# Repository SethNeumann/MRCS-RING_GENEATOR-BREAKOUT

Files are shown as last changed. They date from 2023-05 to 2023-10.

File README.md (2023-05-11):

# REPO NAME: MRCS-RING_GENERATOR-BREAKOUT
## License: Creative Commons Attribution-NonCommercial-ShareAlike

Board for potted ring generator module. Mounts in 70mm Tyco Track (MD) inputs power (screw term and barrel jack), output, straps to select frequency,
optionally add pads for other varieties. The modules are long since MD and data sheets are not available for the PCR-SIN01=V12F00A which I bought oneBay
some suppliers claim to have them.

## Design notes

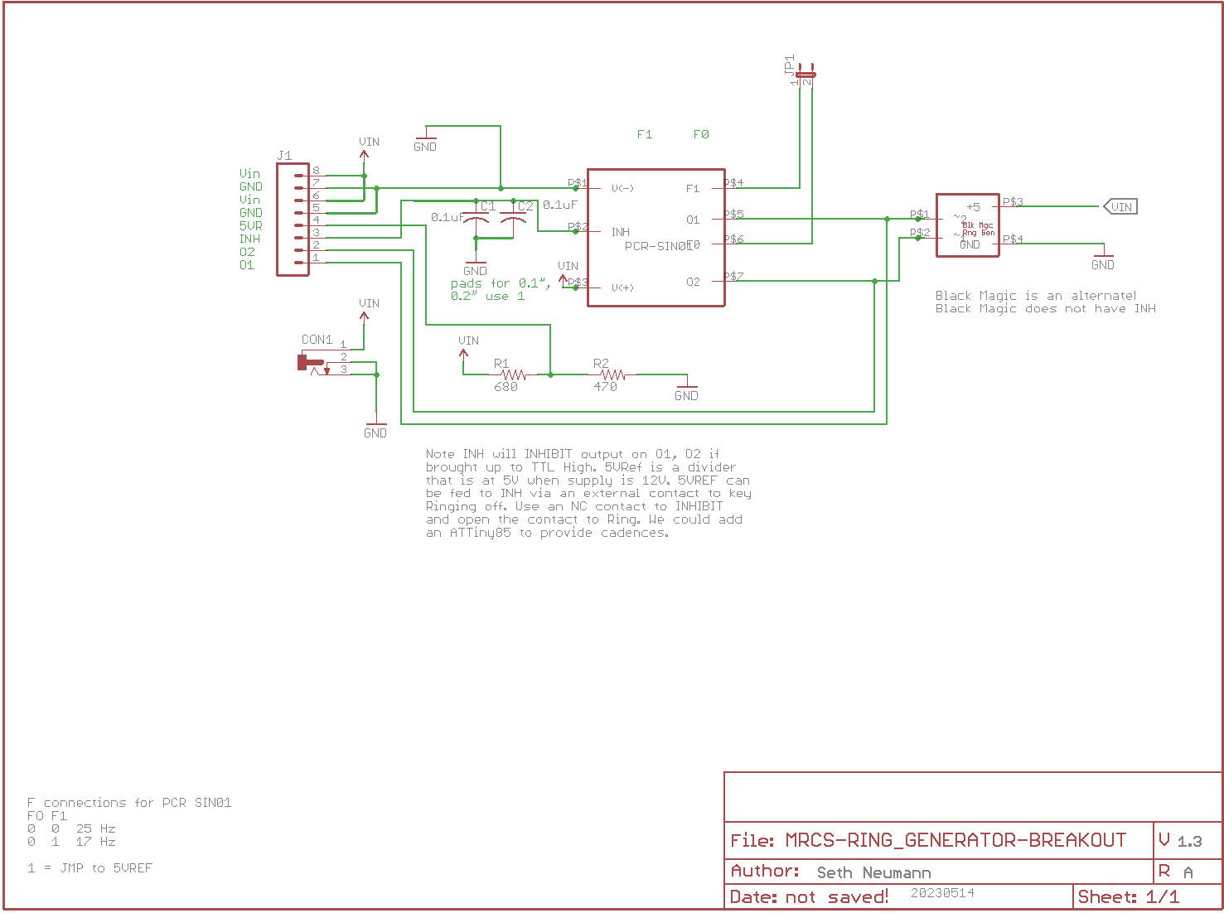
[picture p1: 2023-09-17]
Ringing Generator Schematic V1_3.png

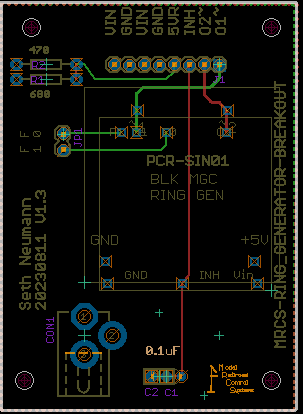
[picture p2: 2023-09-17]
Ringing Generator top layout V1_3.png

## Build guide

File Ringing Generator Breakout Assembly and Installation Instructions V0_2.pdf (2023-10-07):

Page 1 | www.modelrailroadcontrolsystems.com | Sept 17, 2023

# Ringing Generator Module Break Out Board

Revision 0.2 10/07/2023

Seth Neumann, seth@modelrailroadcontrolsystems.com

This document describes the Ringing Generator Module Break Out Board and how to assemble and install it. This board provides a convenient mounting for several types of PowerDsine ™ and Black Magic ™ modules which produce 20Hz ringing signals from 5- or 12-volt DC inputs. As far as I can tell, these modules are all out of production, but they appear for sale on eBay and Telephone Collectors’ lists from time to time. These are handy for demonstrations, model railroad dispatching systems and community theatre applications.

Revision History
V0.1 – first pass – September 17, 2023
V0.2 – minor changes – October 7, 2023

## Table of Contents

7.1. 12

## Table of Figures

## Table of Tables

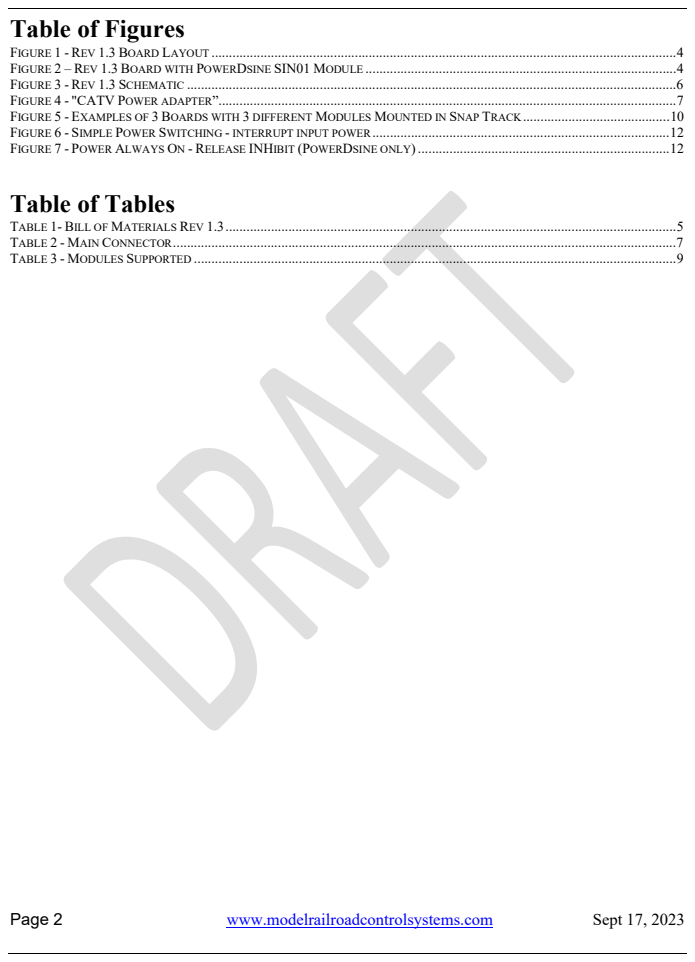
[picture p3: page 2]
Page 2; www.modelrailroadcontrolsystems.com; Sept 17, 2023

FIGURE 1 - REV 1.3 BOARD LAYOUT ..................................................................................................................................... 4
FIGURE 2 – REV 1.3 BOARD WITH POWERDSINE SIN01 MODULE ......................................................................................... 4
FIGURE 3 - REV 1.3 SCHEMATIC ............................................................................................................................................ 6
FIGURE 4 - "CATV POWER ADAPTER”................................................................................................................................... 7
FIGURE 5 - EXAMPLES OF 3 BOARDS WITH 3 DIFFERENT MODULES MOUNTED IN SNAP TRACK .......................................... 10
FIGURE 6 - SIMPLE POWER SWITCHING - INTERRUPT INPUT POWER ..................................................................................... 12
FIGURE 7 - POWER ALWAYS ON - RELEASE INHIBIT (POWERDSINE ONLY) ........................................................................ 12

TABLE 1- BILL OF MATERIALS REV 1.3 ................................................................................................................................. 5
TABLE 2 - MAIN CONNECTOR ................................................................................................................................................ 7
TABLE 3 - MODULES SUPPORTED .......................................................................................................................................... 9

Page 3 | www.modelrailroadcontrolsystems.com | Sept 17, 2023

### 1 INTRODUCTION

This document describes the Ringing Generator Module Break Out Board and how to assemble and install it. This board provides a convenient mounting for several types of PowerDsine ™ and Black Magic ™ modules which produce 20Hz sinewave ringing signals from 5- or 12-volt DC inputs. As far as I can tell, these modules are out of production, but they appear for sale on eBay and Telephone Collectors’ lists from time to time. These are handy for demonstrations, model railroad dispatching systems and community theatre applications.

- Small Footprint 2 x 2.75” (5x7 CM) by ~ .5” high depending on module used.
- Fits in MRCS standard 7CM “Snap Track”
- Power connections on 2.54 mm screw terminals or 2.1mm Barrel Jack. One 12V "Wall Wart" can be daisy chained to power several adapters using the 12V screw terminal connections.
- Supports the Inhibit (INH) function on PowerDsine modules and a voltage divider provides a convenient 5V reference voltage so that an external contact (NC to inhibit) can gate ringing.
- Available as a panel of two bare boards, you supply the module. If you have modules but want us to assemble it, please contact us at sales@modelrailroadcontrolsystems.com

Schematic, circuit board layouts and CAD files are available on the product page on our website and on my GitHub page https://github.com/SethNeumann.

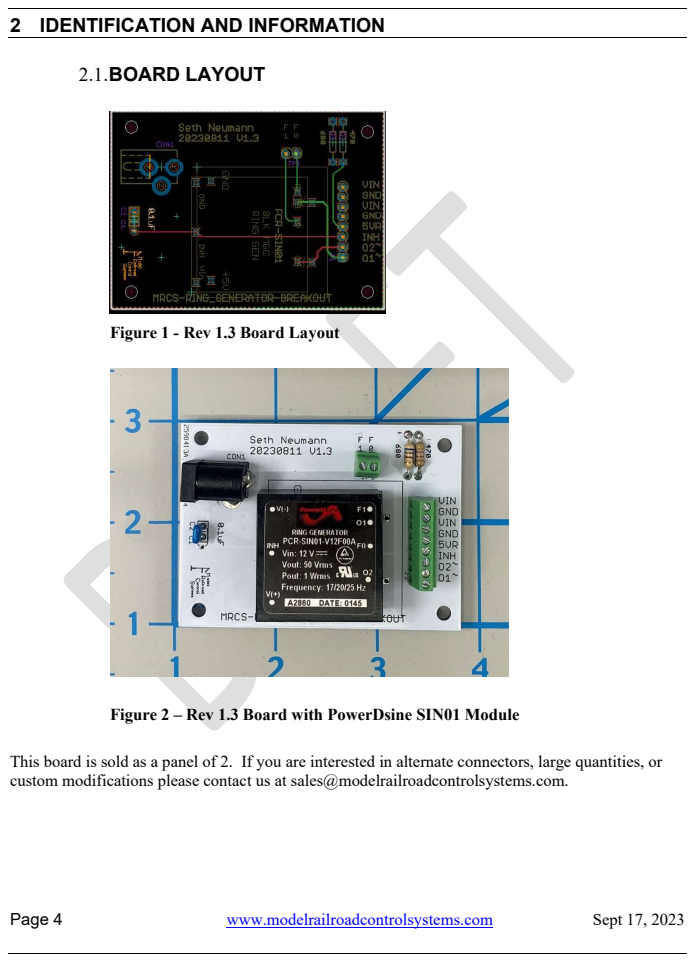
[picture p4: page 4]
Page 4; www.modelrailroadcontrolsystems.com; Sept 17, 2023; 2.1.BOARD LAYOUT

2 IDENTIFICATION AND INFORMATION

Figure 1 - Rev 1.3 Board Layout

Figure 2 – Rev 1.3 Board with PowerDsine SIN01 Module

This board is sold as a panel of 2. If you are interested in alternate connectors, large quantities, or
custom modifications please contact us at sales@modelrailroadcontrolsystems.com.

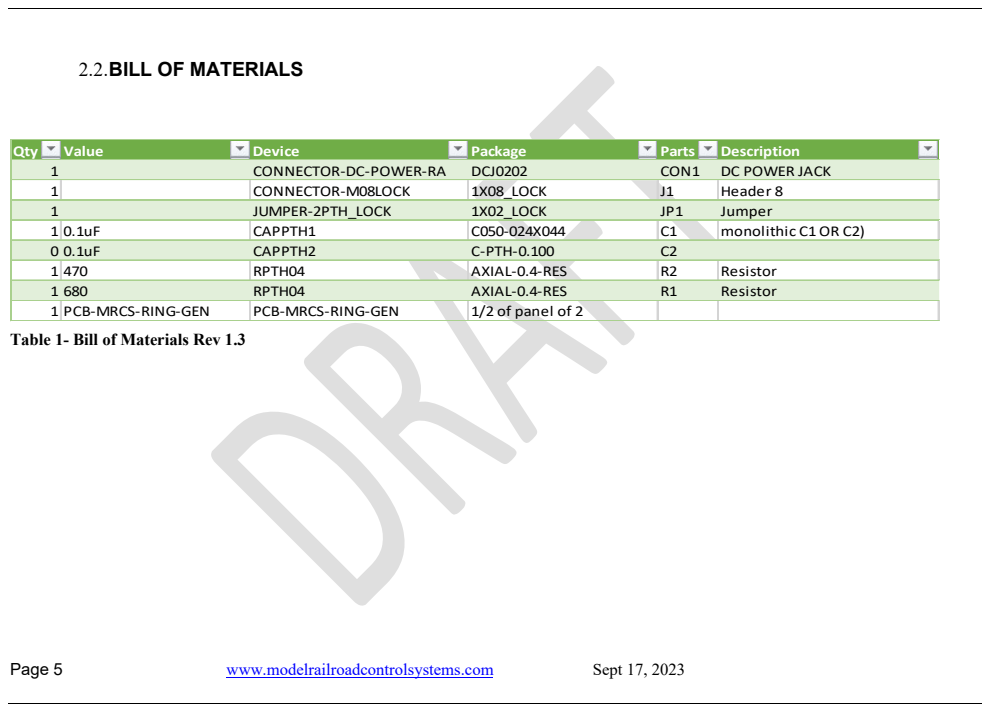
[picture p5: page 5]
Page 5; www.modelrailroadcontrolsystems.com; Sept 17, 2023; Qty; Value; Device; Package; Parts; Description; CONNECTOR-DC-POWER-RA; DCJ0202; CON1 DC POWER JACK; CONNECTOR-M08LOCK; 1X08_LOCK; Header 8; JUMPER-2PTH_LOCK; 1X02_LOCK; Jumper; CAPPTH1; monolithic C1 OR C2); CAPPTH2; C-PTH-0.100; RPTH04; AXIAL-0.4-RES; Resistor; 1 PCB-MRCS-RING-GEN; PCB-MRCS-RING-GEN; 1/2 of panel of 2

2.2.BILL OF MATERIALS

Table 1- Bill of Materials Rev 1.3

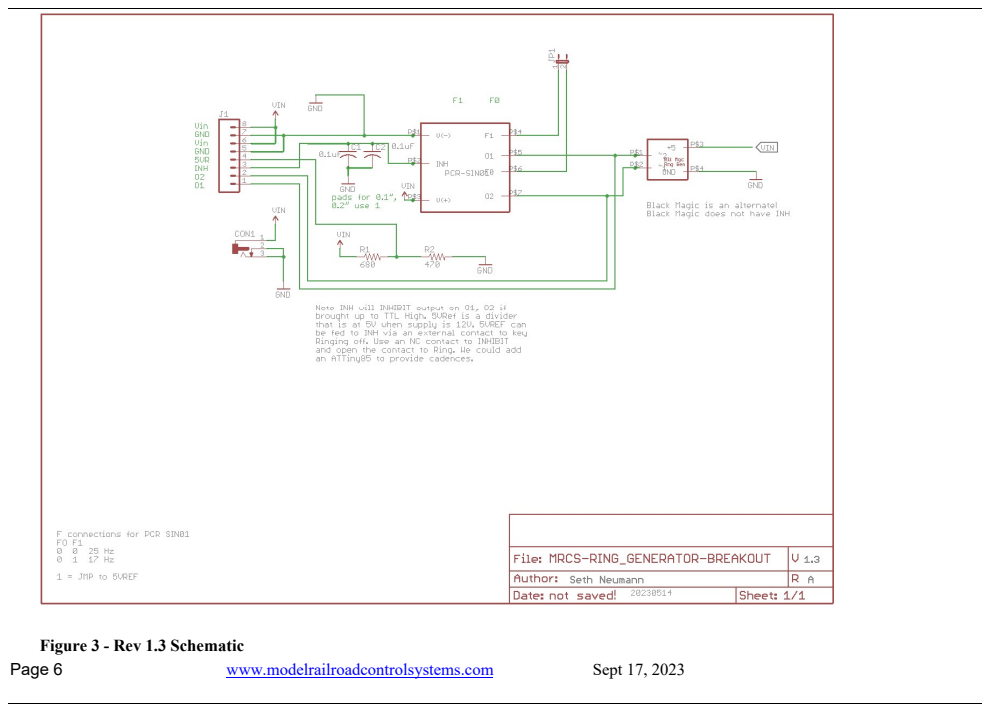
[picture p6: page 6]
Page 6; www.modelrailroadcontrolsystems.com; Sept 17, 2023

Figure 3 - Rev 1.3 Schematic

Page 7 | www.modelrailroadcontrolsystems.com | Sept 17, 2023

### 3 OPTIONS

3.1.CONNECTORS

The main (J1) Connector is on 2.54mm (0.100”) centers. The +V and GND inputs are in parallel with the 2.1 x 5.5 mm. barrel jack and may be used to daisy chain power among multiple Ring Generator breakouts or other 12V loads, subject to the capacity of the 12V wall wart. Note that some Black Magic ™ devices require 5V, so check, also check the current requirements of your module (see table below), if so just use a 5V power supply.

You can omit the barrel jack if wiring directly from a 12VDC auxiliary bus. You can also use a “CATV Power adapter” to plug power from an power auxiliary bus into the barrel jack.

Figure 4 - "CATV Power adapter”

Designation | Comment
VIN | Input Voltage – select for your module, in parallel with DC Power Jack
GND | Negative connection, usually ground
VIN | Input Voltage – select for your module, in parallel with DC Power Jack
GND | Negative connection, usually ground
5VR | For PowerDsine modules – center of voltage divider to INHibit ringing
INH | INHIBIT: Apply 5V here to inhibit ringing, can also use external logic level device such as an Arduino to generate arbitrary ring cadences. Be sure to ground the Arduino and ringing generator breakout together.
O2~ | AC output 20/25~ at 50-85V depending on module
O1~ | AC output 20/25~ at 50-85V depending on module

Table 2 - Main Connector

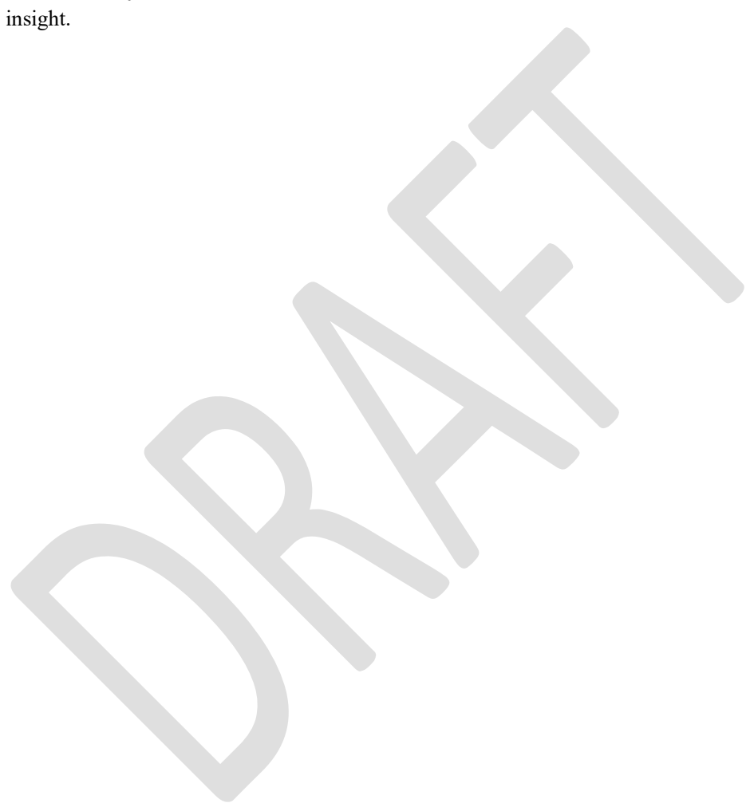
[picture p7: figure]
insight.

Page 8 | www.modelrailroadcontrolsystems.com | Sept 17, 2023

3.2.FREQUENCY SELECTION (PCR-SIN01ONLY)

The PCR-SIN01 states on the case that it can operate at 16.7/20/25 Hz. Perusal of SIN06 (I don’t have an example to test) documentation suggests that tying F0/F1 to 5V will result in other frequencies. I found that the SIN01 with F0/F1 left floating will produce 25 Hz ringing (works fine for a straight-line ringer) and tying F1 to 5VR results in 16.7 Hz. I wasn’t able to get F0 to do anything. Interestingly, grounding F1 produced the same (16.7Hz) result, but the DC position was offset slightly. Connecting both to 5VR also produced 16.7 Hz. My sample(s) may have been defective or there may be some other function of F0 that I am unaware of. Please contact me at the email address above if you have any

Page 9 | www.modelrailroadcontrolsystems.com | Sept 17, 2023

### 4 ASSEMBLY

All components are through-hole technology with wire leads for ease of DIY assembly. The general rule is to install the lowest components first, working towards components that are higher off the board. This enables you to support the low components as you solder them. The suggested order assumes you are using the barrel connector. If you choose to use different connectors, check the heights, and vary the build order accordingly.

[ ] Resistors

[ ] Install resistors R1, R2, these are voltage divider that yields ~5V with a 12V input. If you are using Black Magic ™ modules, not using the inhibit function or are using an Arduino or other logic level device to control the output, you can omit the resistors.

[ ] Screw Terminals

[ ] Install J1. This is an 8 position 2.54 mm screw terminal. Note that only the O1~ and O2~ terminals are required. If you aren’t using the INHibit function and don’t need to daisy chain power, the other positions can be left open and a 2 position terminal may be used.
[ ] Install the 2 position jumper or screw terminal for F0/F1. This is used by the PowerDsine PCR-SIN01-V12F00A. Most users will omit this connector.

[ ] Capacitors

C1 and C2 are alternates at 0.1” or 0.2” spacing and provide noise protection on the INHibit line. You can omit them for Black Magic ™ modules. I use monolithic caps for this application, and they come in both footprints

[ ] Barrel Jack

[ ] Install the DC Power barrel jack, if used

[ ] Ring Generator Module

[ ] Install your ringing generator module with pads provided. (I made EAGLE CAD “Library models” of the various modules I have. Contact me if you have something different and I can probably make a model for it and make a board version using it).

Module | INH? | Input V | Input Current Idle | Input Current Active | Ring Volts Out | Nominal Freq/Func
PowerDsine PCR SIN01 | Y | 12 VDC | 52 mA @ 12V | 270 mA | 50 VAC | 25 Hz Sine
PowerDsine PCR SQR05 | Y | 12 VDC | 63 mA @ 12V | 325 mA | 70 VAC | 20 Hz Square
Black Magic | N | 5VDC | 165 mA @ 5V | 1.05 A @ 5V | 86 VAC | 20 Hz Square

Table 3 - Modules Supported

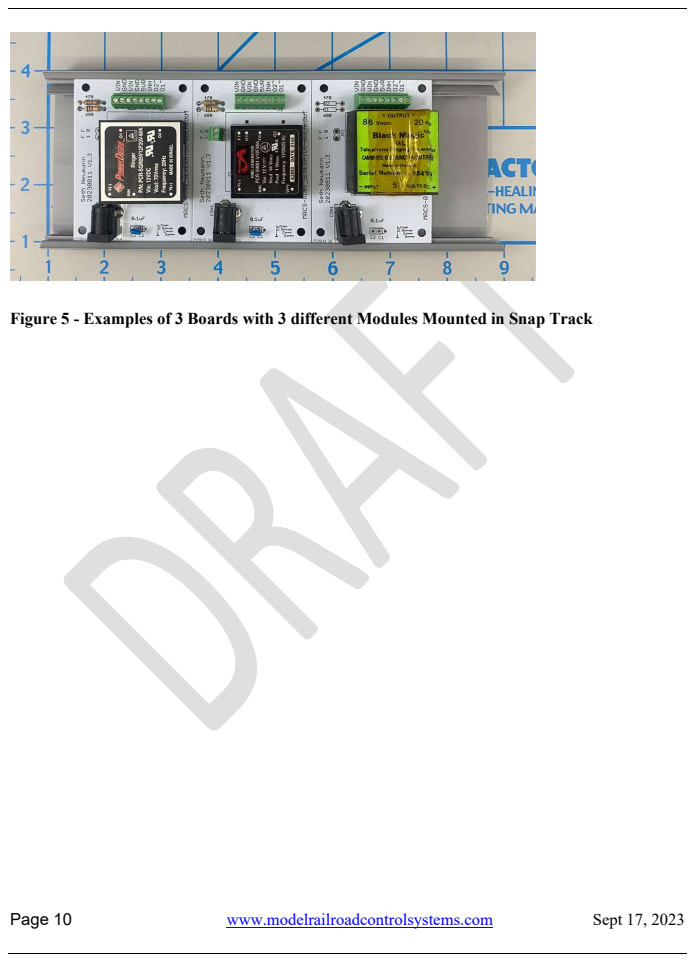
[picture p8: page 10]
Page 10; www.modelrailroadcontrolsystems.com; Sept 17, 2023

Figure 5 - Examples of 3 Boards with 3 different Modules Mounted in Snap Track

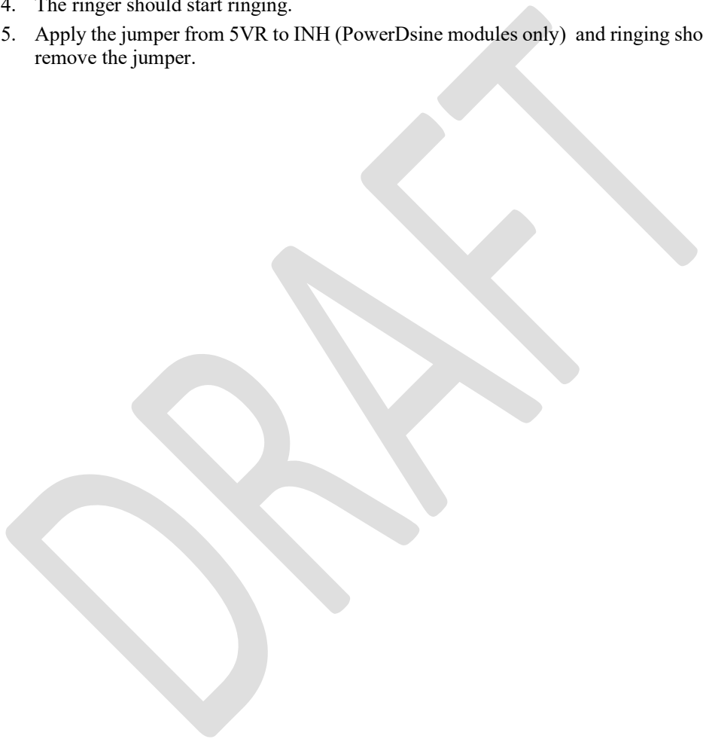
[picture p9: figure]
remove the jumper.

Page 11 | www.modelrailroadcontrolsystems.com | Sept 17, 2023

### 5 TESTING

Testing your Ringing Generator board is quick and simple:

1. Connect a suitable ringer (say a C4A from a 500 set or just put a 500 set) across the O1~ and O2~ terminals.
2. Prepare a jumper wire with one end in the 5VR terminal and the other stripped.
3. Apply power (as determined by your module) to either the barrel jack or the screw terminal.
4. The ringer should start ringing.
5. Apply the jumper from 5VR to INH (PowerDsine modules only) and ringing should stop until you

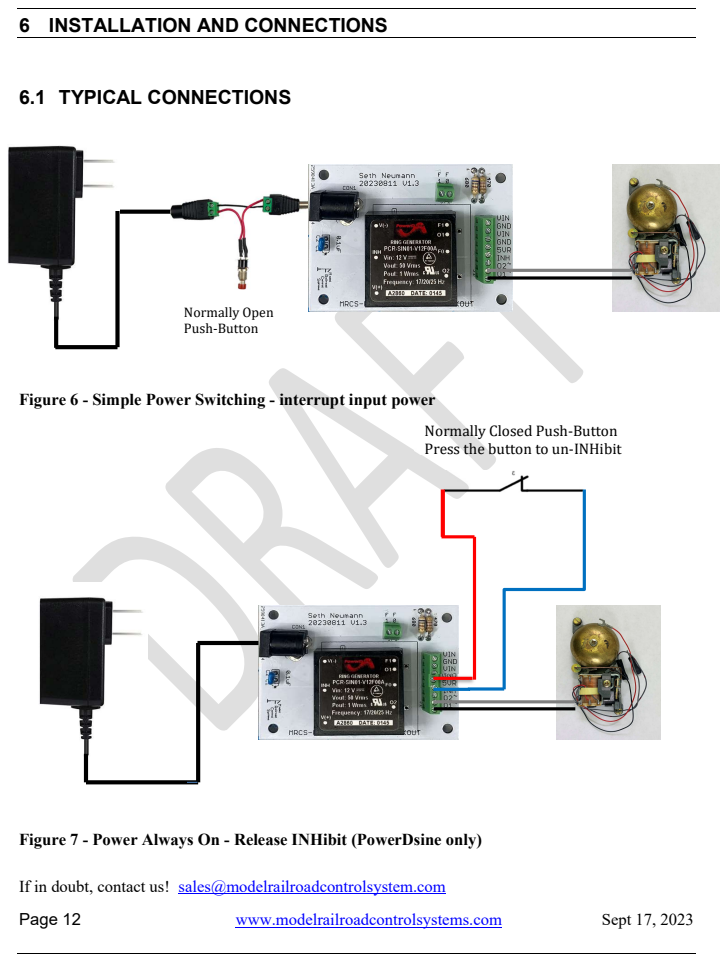
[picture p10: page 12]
Page 12; www.modelrailroadcontrolsystems.com; Sept 17, 2023; 6.1 TYPICAL CONNECTIONS; Normally Open Push-Button

6 INSTALLATION AND CONNECTIONS

Figure 6 - Simple Power Switching - interrupt input power

Normally Closed Push-Button
Press the button to un-INHibit

Figure 7 - Power Always On - Release INHibit (PowerDsine only)

If in doubt, contact us! sales@modelrailroadcontrolsystem.com

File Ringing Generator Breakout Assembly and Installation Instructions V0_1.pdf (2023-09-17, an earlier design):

Page 1 | www.modelrailroadcontrolsystems.com | Sept 17, 2023

# Ringing Generator Module Break Out Board

Revision 0.1 09/17/2023

Seth Neumann, seth@modelrailroadcontrolsystems.com

This document describes the Ringing Generator Module Break Out Board and how to assemble and install it. This board provides a convenient mounting for several types of PowerDsine ™ and Black Magic ™ modules which produce 20Hz ringing signals from 5- or 12-volt DC inputs. As far as I can tell, these modules are all out of production, but they appear for sale on eBay and Telephone Collectors’ lists from time to time. These are handy for demonstrations, model railroad dispatching systems and community theatre applications.

Revision History
V0.1 – first pass – September 17, 2023

## Table of Contents

7.1. 12

## Table of Figures

## Table of Tables

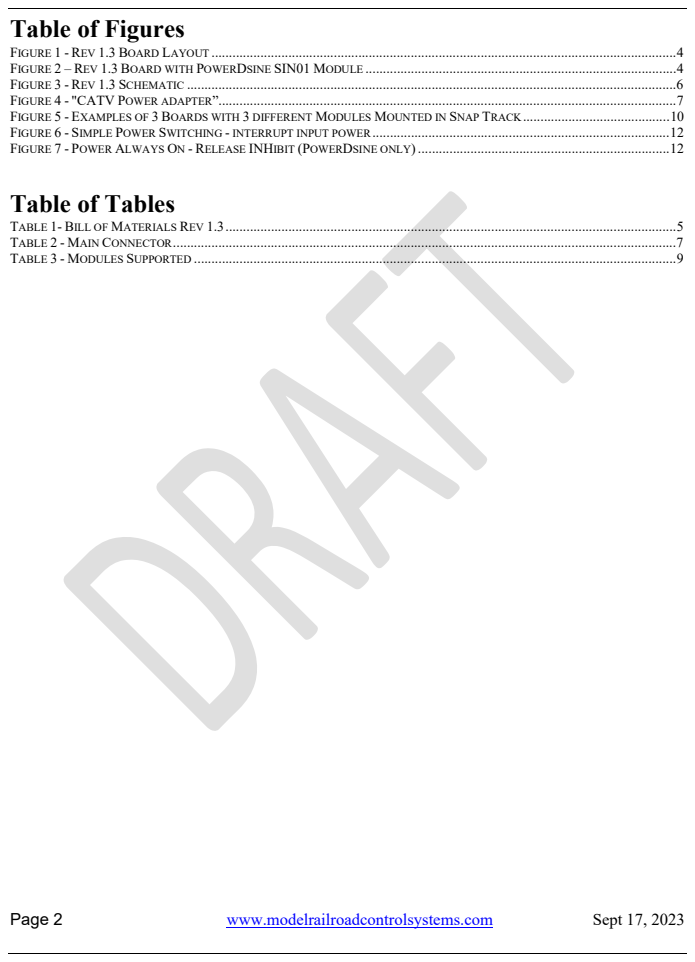
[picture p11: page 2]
Page 2; www.modelrailroadcontrolsystems.com; Sept 17, 2023

FIGURE 1 - REV 1.3 BOARD LAYOUT ..................................................................................................................................... 4
FIGURE 2 – REV 1.3 BOARD WITH POWERDSINE SIN01 MODULE ......................................................................................... 4
FIGURE 3 - REV 1.3 SCHEMATIC ............................................................................................................................................ 6
FIGURE 4 - "CATV POWER ADAPTER”................................................................................................................................... 7
FIGURE 5 - EXAMPLES OF 3 BOARDS WITH 3 DIFFERENT MODULES MOUNTED IN SNAP TRACK .......................................... 10
FIGURE 6 - SIMPLE POWER SWITCHING - INTERRUPT INPUT POWER ..................................................................................... 12
FIGURE 7 - POWER ALWAYS ON - RELEASE INHIBIT (POWERDSINE ONLY) ........................................................................ 12

TABLE 1- BILL OF MATERIALS REV 1.3 ................................................................................................................................. 5
TABLE 2 - MAIN CONNECTOR ................................................................................................................................................ 7
TABLE 3 - MODULES SUPPORTED .......................................................................................................................................... 9

Page 3 | www.modelrailroadcontrolsystems.com | Sept 17, 2023

### 1 INTRODUCTION

This document describes the Ringing Generator Module Break Out Board and how to assemble and install it. This board provides a convenient mounting for several types of PowerDsine ™ and Black Magic ™ modules which produce 20Hz sinewave ringing signals from 5- or 12-volt DC inputs. As far as I can tell, these modules are out of production, but they appear for sale on eBay and Telephone Collectors’ lists from time to time. These are handy for demonstrations, model railroad dispatching systems and community theatre applications.

- Small Footprint 2 x 2.75” (5x7 CM) by ~ .5” high depending on module used.
- Fits in MRCS standard 7CM “Snap Track”
- Power connections on 2.54 mm screw terminals or 2.1mm Barrel Jack. One 12V "Wall Wart" can be daisy chained to power several adapters using the 12V screw terminal connections.
- Supports the Inhibit (INH) function on PowerDsine modules and a voltage divider provides a convenient 5V reference voltage so that an external contact (NC to inhibit) can gate ringing.
- Available as a panel of two bare boards, you supply the module. If you have modules but want us to assemble it, please contact us at sales@modelrailroadcontrolsystems.com

Schematic, circuit board layouts and CAD files are available on the product page on our website and on my GitHub page https://github.com/SethNeumann.

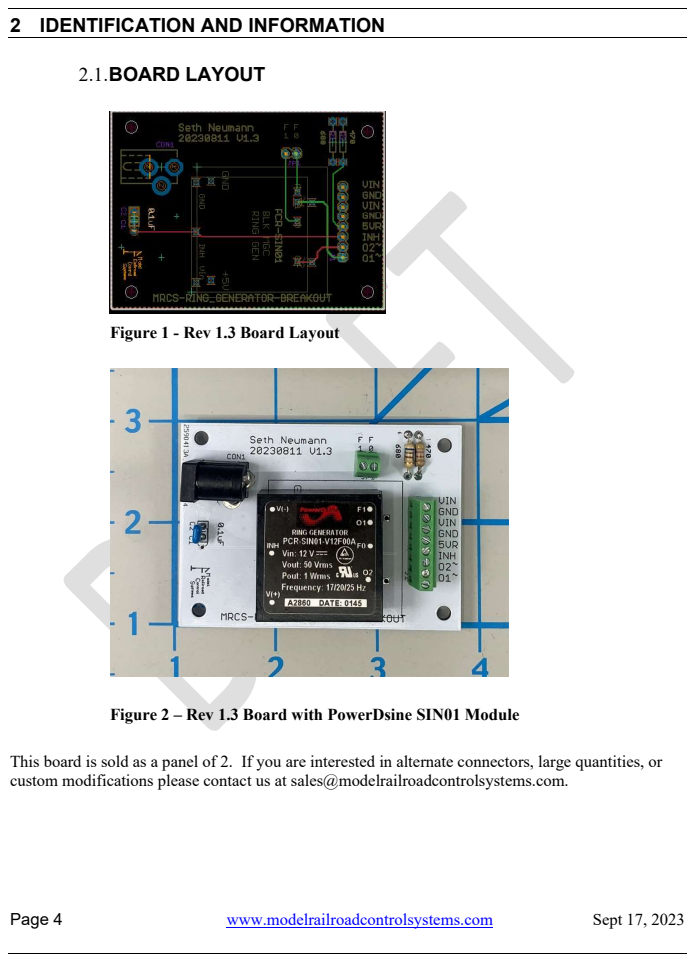
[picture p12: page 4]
Page 4; www.modelrailroadcontrolsystems.com; Sept 17, 2023; 2.1.BOARD LAYOUT

2 IDENTIFICATION AND INFORMATION

Figure 1 - Rev 1.3 Board Layout

Figure 2 – Rev 1.3 Board with PowerDsine SIN01 Module

This board is sold as a panel of 2. If you are interested in alternate connectors, large quantities, or
custom modifications please contact us at sales@modelrailroadcontrolsystems.com.

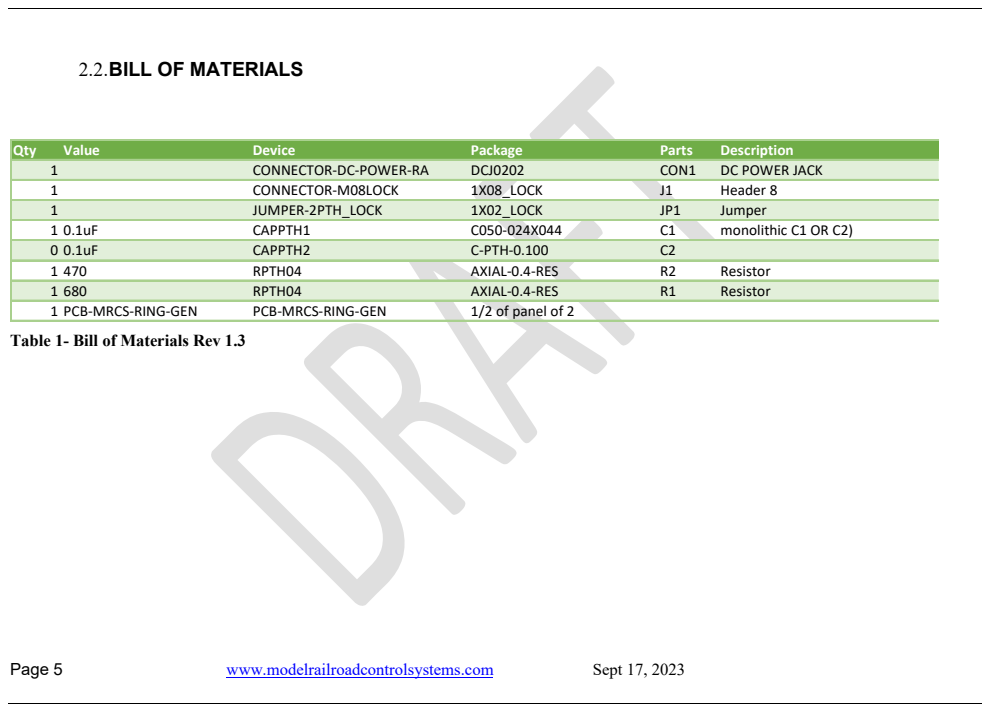
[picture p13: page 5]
Page 5; www.modelrailroadcontrolsystems.com; Sept 17, 2023; Qty; Value; Device; Package; Parts; Description; CONNECTOR-DC-POWER-RA; DCJ0202; CON1; DC POWER JACK; CONNECTOR-M08LOCK; 1X08_LOCK; Header 8; JUMPER-2PTH_LOCK; 1X02_LOCK; Jumper; CAPPTH1; monolithic C1 OR C2); CAPPTH2; C-PTH-0.100; RPTH04; AXIAL-0.4-RES; Resistor; 1 PCB-MRCS-RING-GEN; PCB-MRCS-RING-GEN; 1/2 of panel of 2

2.2.BILL OF MATERIALS

Table 1- Bill of Materials Rev 1.3

Page 6; www.modelrailroadcontrolsystems.com; Sept 17, 2023

Figure 3 - Rev 1.3 Schematic

Page 7 | www.modelrailroadcontrolsystems.com | Sept 17, 2023

### 3 OPTIONS

3.1.CONNECTORS

The main (J1) Connector is on 2.54mm (0.100”) centers. The +V and GND inputs are in parallel with the 2.1 x 5.5 mm. barrel jack and may be used to daisy chain power among multiple Ring Generator breakouts or other 12V loads, subject to the capacity of the 12V wall wart. Note that some Black Magic ™ devices require 5V, so check, also check the current requirements of your module (see table below), if so just use a 5V power supply.

You can omit the barrel jack if wiring directly from a 12VDC auxiliary bus. You can also use a “CATV Power adapter” to plug power from an power auxiliary bus into the barrel jack.

Figure 4 - "CATV Power adapter”

Designation | Comment
VIN | Input Voltage – select for your module, in parallel with DC Power Jack
GND | Negative connection, usually ground
VIN | Input Voltage – select for your module, in parallel with DC Power Jack
GND | Negative connection, usually ground
5VR | For PowerDsine modules – center of voltage divider to INHibit ringing
INH | INHIBIT: Apply 5V here to inhibit ringing, can also use external logic level device such as an Arduino to generate arbitrary ring cadences. Be sure to ground the Arduino and ringing generator breakout together.
O2~ | AC output 20~ at 50-85V depending on module
O1~ | AC output 20~ at 50-85V depending on module

Table 2 - Main Connector

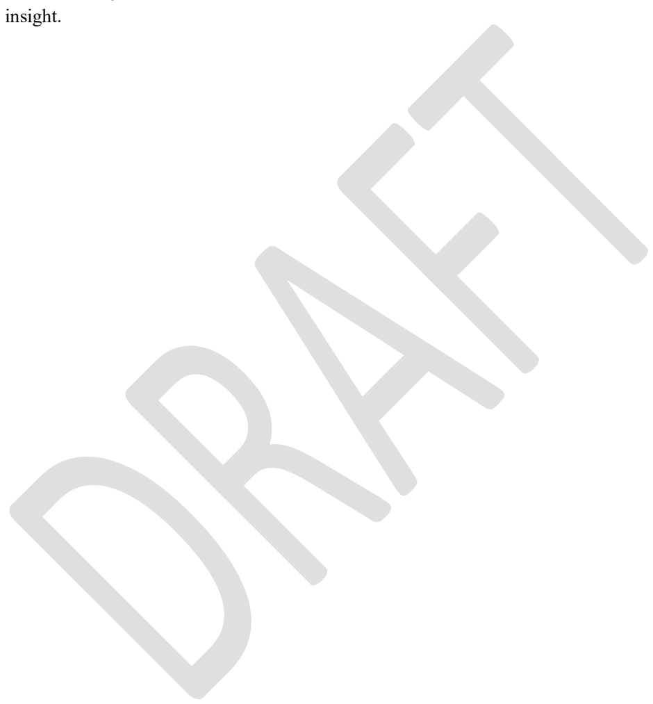
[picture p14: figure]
insight.

Page 8 | www.modelrailroadcontrolsystems.com | Sept 17, 2023

3.2.FREQUENCY SELECTION (PCR-SIN01ONLY)

The PCR-SIN01 states on the case that it can operate at 16.7/20/25 Hz. Perusal of SIN06 (I don’t have an example to test) documentation suggests that tying F0/F1 to 5V will result in other frequencies. I found that the SIN01 with F0/F1 left floating will produce 25 Hz ringing (works fine for a straight-line ringer) and tying F1 to 5VR results in 16.7 Hz. I wasn’t able to get F0 to do anything. Interestingly, grounding F1 produced the same (16.7Hz) result, but the DC position was offset slightly. Connecting both to 5VR also produced 16.7 Hz. My sample(s) may have been defective or there may be some other function of F0 that I am unaware of. Please contact me at the email address above if you have any

Page 9 | www.modelrailroadcontrolsystems.com | Sept 17, 2023

### 4 ASSEMBLY

All components are through-hole technology with wire leads for ease of DIY assembly. The general rule is to install the lowest components first, working towards components that are higher off the board. This enables you to support the low components as you solder them. The suggested order assumes you are using the barrel connector. If you choose to use different connectors, check the heights, and vary the build order accordingly.

[ ] Resistors

[ ] Install resistors R1, R2, these are voltage divider that yields ~5V with a 12V input. If you are using Black Magic ™ modules, not using the inhibit function or are using an Arduino or other logic level device to control the output, you can omit the resistors.

[ ] Screw Terminals

[ ] Install J1. This is an 8 position 2.54 mm screw terminal. Note that only the O1~ and O2~ terminals are required. If you aren’t using the INHibit function and don’t need to daisy chain power, the other positions can be left open and a 2 position terminal may be used.
[ ] Install the 2 position jumper or screw terminal for F0/F1. This is used by the PowerDsine PCR-SIN01-V12F00A. Most users will omit this connector.

[ ] Capacitors

C1 and C2 are alternates at 0.1” or 0.2” spacing and provide noise protection on the INHibit line. You can omit them for Black Magic ™ modules. I use monolithic caps for this application, and they come in both footprints

[ ] Barrel Jack

[ ] Install the DC Power barrel jack, if used

[ ] Ring Generator Module

[ ] Install your ringing generator module with pads provided. (I made EAGLE CAD “Library models” of the various modules I have. Contact me if you have something different and I can probably make a model for it and make a board version using it).

Module | INH? | Input V | Input Current Idle | Input Current Active | Ring Volts Out | Nominal Freq/Func
PowerDsine PCR SIN01 | Y | 12 VDC | 52 mA @ 12V | 270 mA | 50 VAC | 25 Hz Sine
PowerDsine PCR SQR05 | Y | 12 VDC | 63 mA @ 12V | 325 mA | 70 VAC | 20 Hz Square
Black Magic | N | 5VDC | 165 mA @ 5V | 1.05 A @ 5V | 86 VAC | 20 Hz Square

Table 3 - Modules Supported

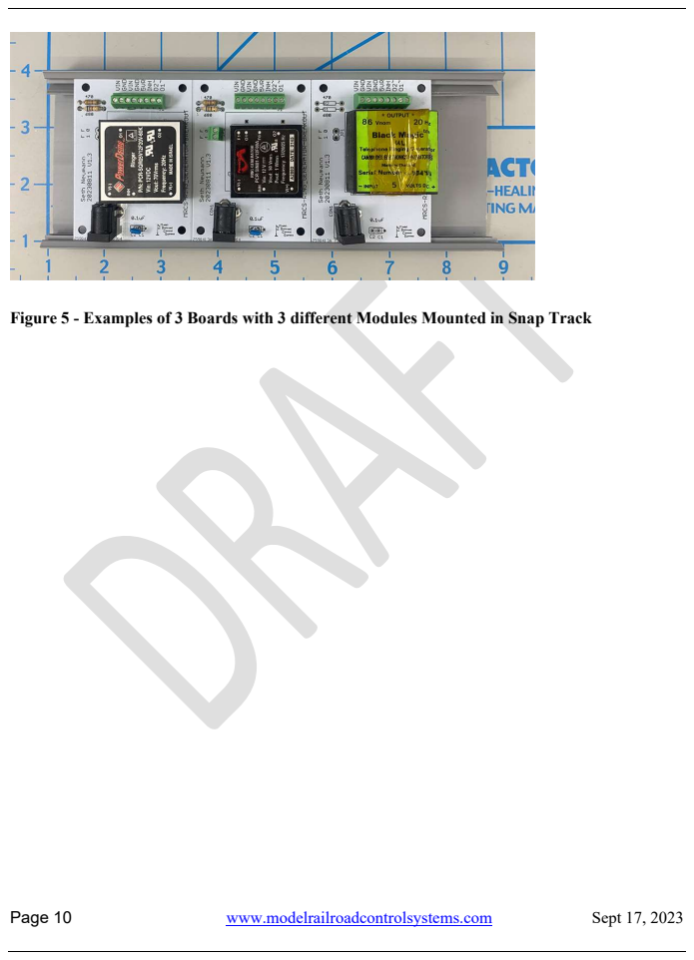
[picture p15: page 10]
Page 10; www.modelrailroadcontrolsystems.com; Sept 17, 2023

Figure 5 - Examples of 3 Boards with 3 different Modules Mounted in Snap Track

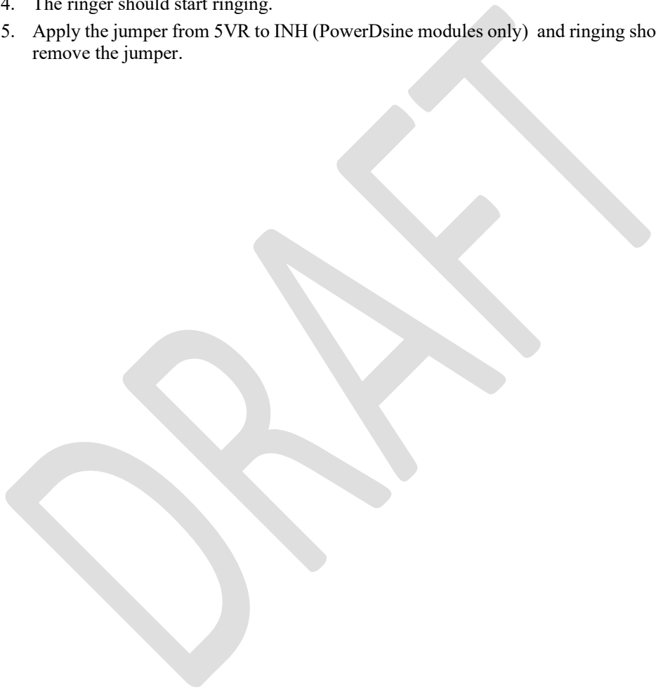
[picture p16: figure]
remove the jumper.

Page 11 | www.modelrailroadcontrolsystems.com | Sept 17, 2023

### 5 TESTING

Testing your Ringing Generator board is quick and simple:

1. Connect a suitable ringer (say a C4A from a 500 set or just put a 500 set) across the O1~ and O2~ terminals.
2. Prepare a jumper wire with one end in the 5VR terminal and the other stripped.
3. Apply power (as determined by your module) to either the barrel jack or the screw terminal.
4. The ringer should start ringing.
5. Apply the jumper from 5VR to INH (PowerDsine modules only) and ringing should stop until you

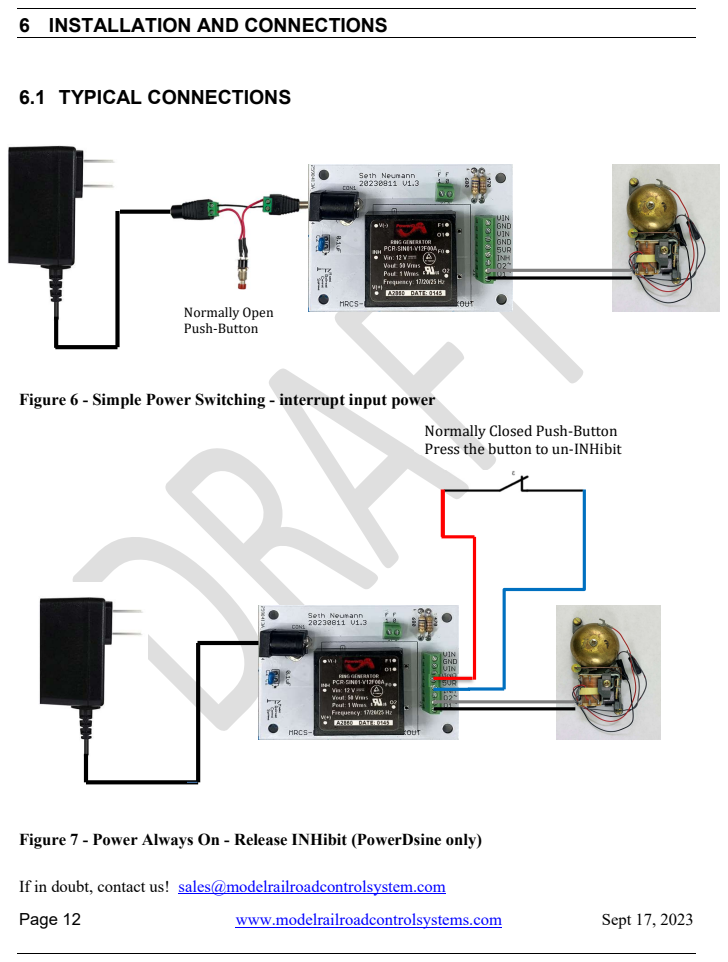
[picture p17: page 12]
Page 12; www.modelrailroadcontrolsystems.com; Sept 17, 2023; 6.1 TYPICAL CONNECTIONS; Normally Open Push-Button

6 INSTALLATION AND CONNECTIONS

Figure 6 - Simple Power Switching - interrupt input power

Normally Closed Push-Button
Press the button to un-INHibit

Figure 7 - Power Always On - Release INHibit (PowerDsine only)

If in doubt, contact us! sales@modelrailroadcontrolsystem.com

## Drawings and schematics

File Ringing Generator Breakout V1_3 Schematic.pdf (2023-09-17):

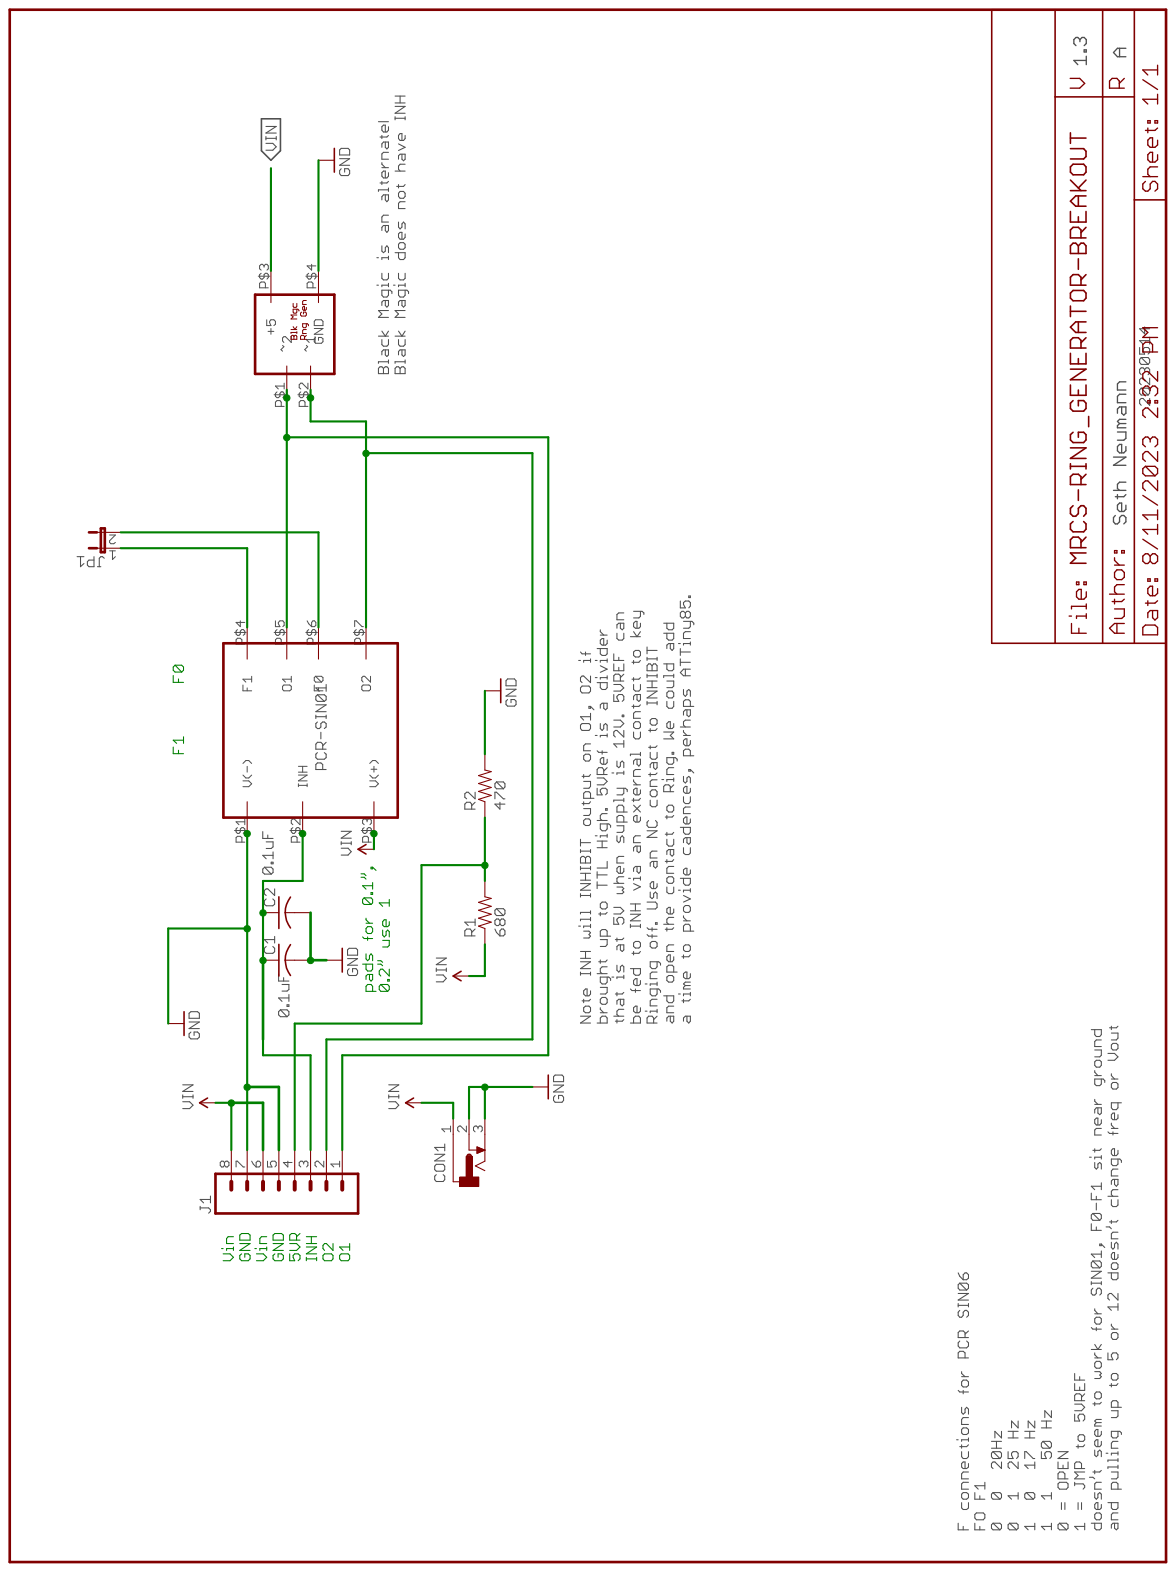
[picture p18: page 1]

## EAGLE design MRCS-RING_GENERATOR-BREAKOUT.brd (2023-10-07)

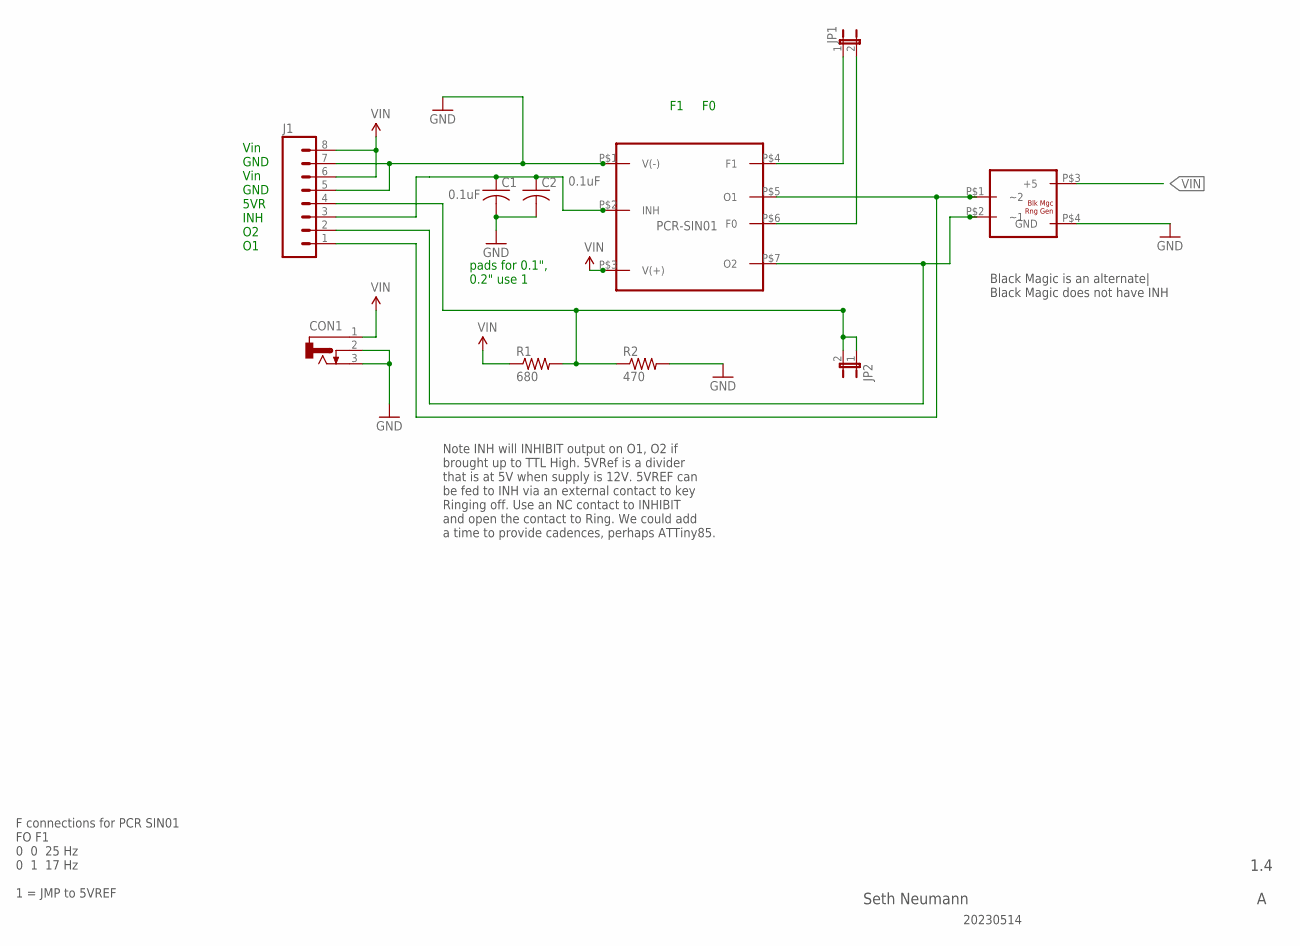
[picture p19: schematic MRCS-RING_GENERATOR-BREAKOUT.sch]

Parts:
C1: 0.1uF; C050-024X044
C2: 0.1uF; C-PTH-0.100
CON1: CONNECTOR-DC-POWER-RA; DCJ0202
J1: CONNECTOR-M08LOCK; 1X08_LOCK
JP1, JP2: JUMPER-2PTH_LOCK; 1X02_LOCK
R1: 680; AXIAL-0.4-RES
R2: 470; AXIAL-0.4-RES
U$1: PCR-SIN01
U$5: BLACK_MAGIC_RING_GEN

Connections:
5VREF: J1.4, JP2.1, JP2.2, R1.P$2 (2), R2.P$1 (1)
F0: JP1.2, U$1.P$6 (F0)
F1: JP1.1, U$1.P$4 (F1)
GND: C1.2, C2.2, CON1.2, CON1.3, J1.5, J1.7, R2.P$2 (2), U$1.P$1 (V(-)), U$5.P$4 (GND)
INH: C1.1, C2.1, J1.3, U$1.P$2 (INH)
O1: J1.1, U$1.P$5 (O1), U$5.P$1 (~2)
O2: J1.2, U$1.P$7 (O2), U$5.P$2 (~1)
VIN: CON1.1, J1.6, J1.8, R1.P$1 (1), U$1.P$3 (V(+)), U$5.P$3 (+5)

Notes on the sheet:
1.4
Seth Neumann
F connections for PCR SIN01 FO F1 0 0 25 Hz 0 1 17 Hz 1 = JMP to 5VREF
F1 F0
pads for 0.1", 0.2" use 1
Vin GND Vin GND 5VR INH O2 O1
Note INH will INHIBIT output on O1, O2 if brought up to TTL High. 5VRef is a divider that is at 5V when supply is 12V. 5VREF can be fed to INH via an external contact to key Ringing off. Use an NC contact to INHIBIT and open the contact to Ring. We could add a time to provide cadences, perhaps ATTi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
Black Magic is an alternate| Black Magic does not have INH
20230514

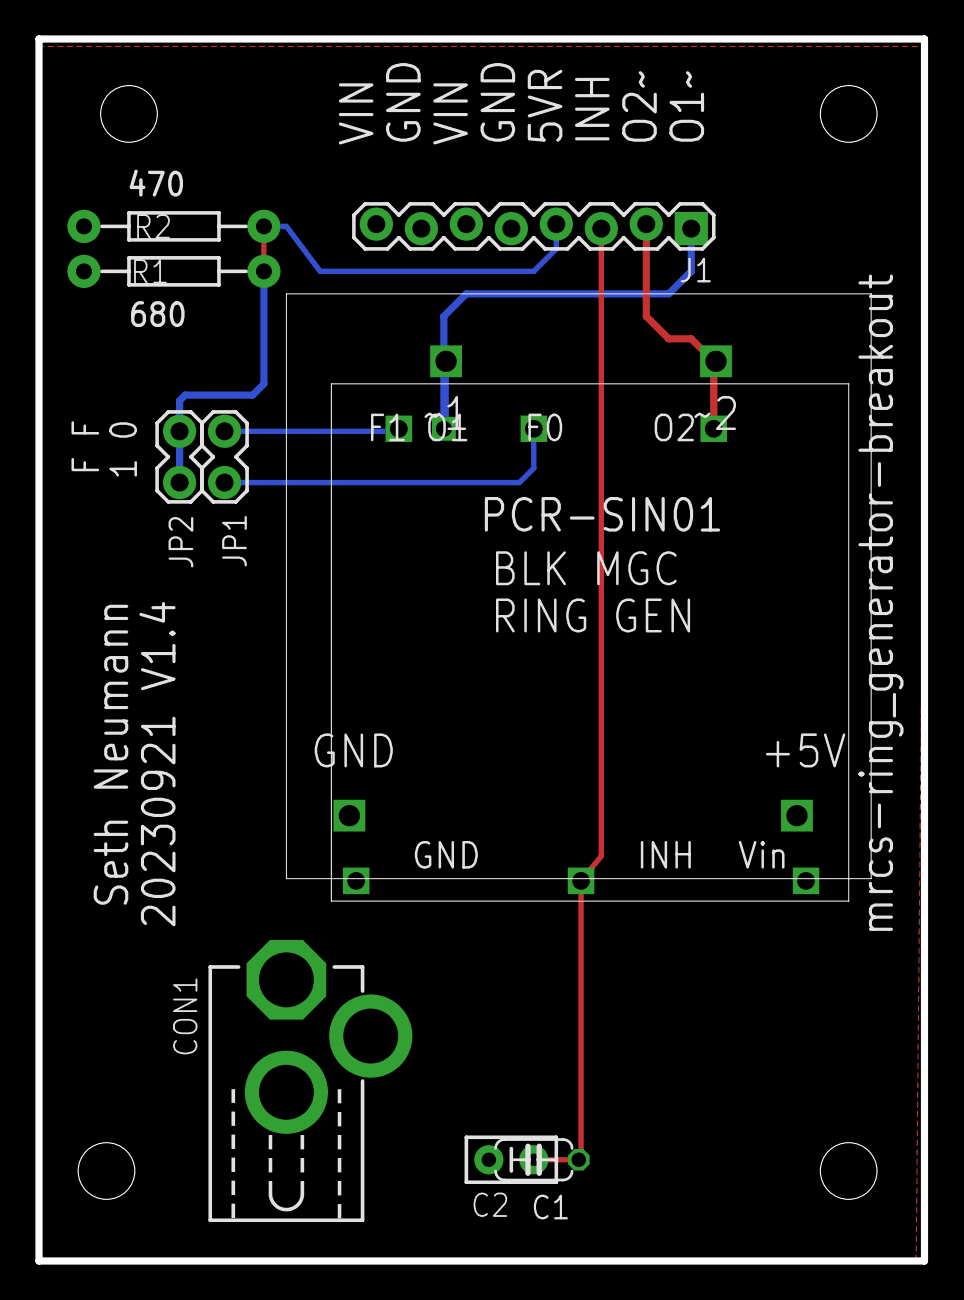
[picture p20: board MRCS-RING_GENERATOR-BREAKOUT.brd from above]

Board: 2 copper layers, 50.0 x 69.0 mm, 13 parts (0 on the bottom side), 8 nets.

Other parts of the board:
U$2: MRCSLOGOTOP
U$3: CA-PROP65WARNING
U$4: MRCSLOGOBTM

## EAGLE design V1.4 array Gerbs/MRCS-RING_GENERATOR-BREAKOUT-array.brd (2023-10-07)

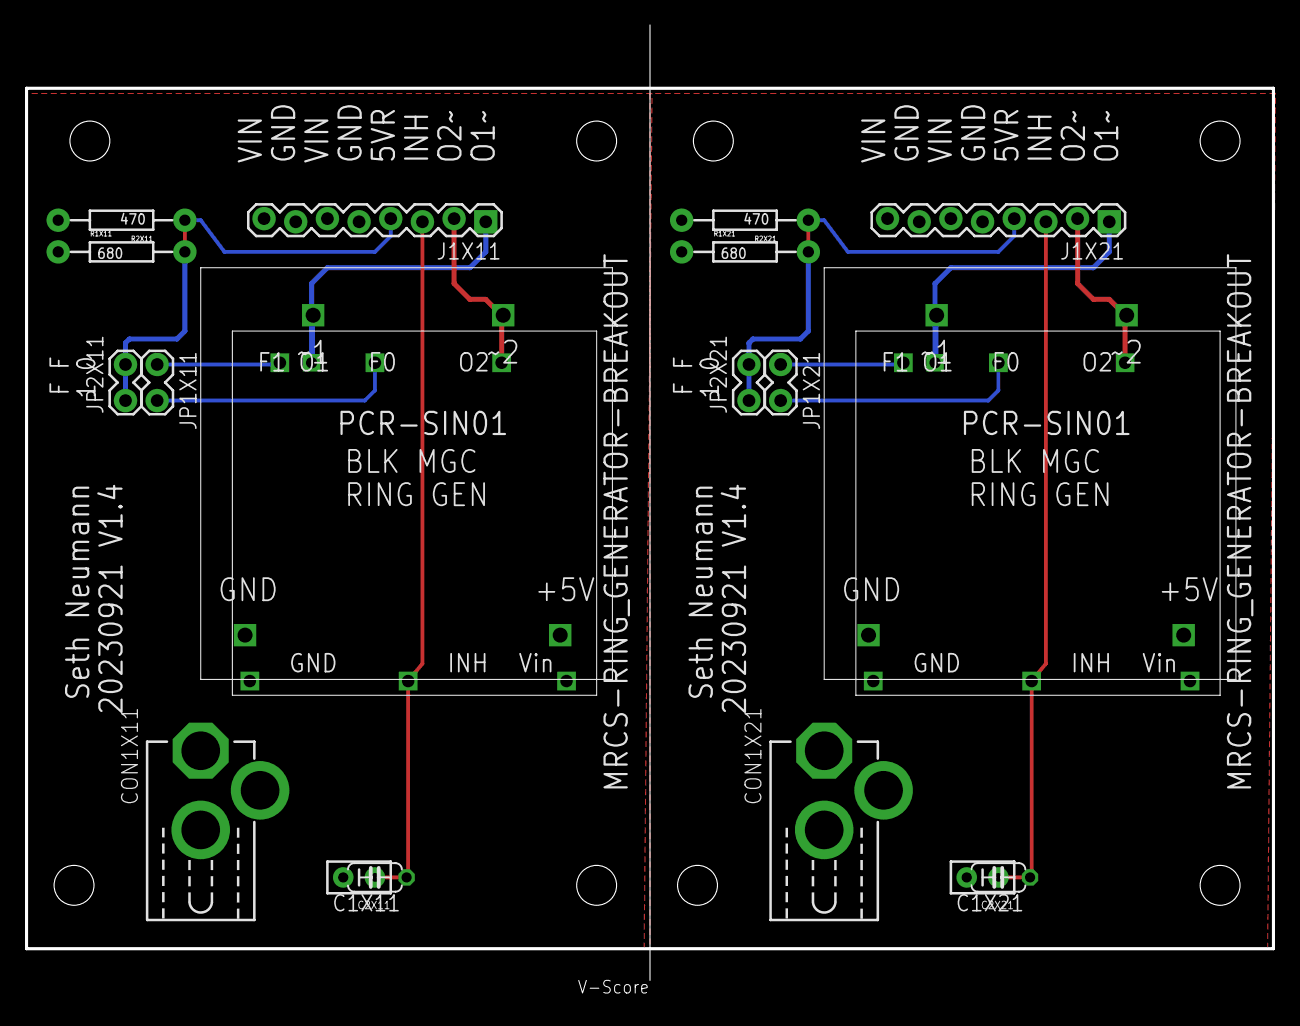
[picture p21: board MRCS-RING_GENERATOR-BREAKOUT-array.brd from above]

Board: 2 copper layers, 100.0 x 69.0 mm, 26 parts (0 on the bottom side), 16 nets.

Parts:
C1X11, C1X21: 0.1uF; C050-024X044
C2X11, C2X21: 0.1uF; C-PTH-0.100
CON1X11, CON1X21: DCJ0202
J1X11, J1X21: 1X08_LOCK
JP1X11, JP1X21, JP2X11, JP2X21: 1X02_LOCK
R1X11, R1X21: 680; AXIAL-0.4-RES
R2X11, R2X21: 470; AXIAL-0.4-RES
U$1X11, U$1X21: PCR-SIN01
U$2X11, U$2X21: MRCSLOGOTOP
U$3X11, U$3X21: CA-PROP65WARNING
U$4X11, U$4X21: MRCSLOGOBTM
U$5X11, U$5X21: BLACK_MAGIC_RING_GEN

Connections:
5VREFX11: J1X11.4, JP2X11.1, JP2X11.2, R1X11.P$2, R2X11.P$1
5VREFX21: J1X21.4, JP2X21.1, JP2X21.2, R1X21.P$2, R2X21.P$1
F0X11: JP1X11.2, U$1X11.P$6
F0X21: JP1X21.2, U$1X21.P$6
F1X11: JP1X11.1, U$1X11.P$4
F1X21: JP1X21.1, U$1X21.P$4
GNDX11: C1X11.2, C2X11.2, CON1X11.2, CON1X11.3, J1X11.5, J1X11.7, R2X11.P$2, U$1X11.P$1, U$5X11.P$4
GNDX21: C1X21.2, C2X21.2, CON1X21.2, CON1X21.3, J1X21.5, J1X21.7, R2X21.P$2, U$1X21.P$1, U$5X21.P$4
INHX11: C1X11.1, C2X11.1, J1X11.3, U$1X11.P$2
INHX21: C1X21.1, C2X21.1, J1X21.3, U$1X21.P$2
O1X11: J1X11.1, U$1X11.P$5, U$5X11.P$1
O1X21: J1X21.1, U$1X21.P$5, U$5X21.P$1
O2X11: J1X11.2, U$1X11.P$7, U$5X11.P$2
O2X21: J1X21.2, U$1X21.P$7, U$5X21.P$2
VINX11: CON1X11.1, J1X11.6, J1X11.8, R1X11.P$1, U$1X11.P$3, U$5X11.P$3
VINX21: CON1X21.1, J1X21.6, J1X21.8, R1X21.P$1, U$1X21.P$3, U$5X21.P$3

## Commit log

2023-05-11 creating working directory
    [MRCS-RING_GENERATOR-BREAKOUT.brd, MRCS-RING_GENERATOR-BREAKOUT.sch]
2023-09-17 Various updates while preparing documentation
    [MRCS-RING_GENERATOR-BREAKOUT.sch]
2023-09-17 Create Ringing Generator Breakout Assembly and Installation Instructions V0_1.pdf
    First Pass documentation
2023-10-07 panelized 2 up version
    [MRCS-RING_GENERATOR-BREAKOUT-array.brd, MRCS-RING_GENERATOR-BREAKOUT.brd, MRCS-RING_GENERATOR-BREAKOUT.sch]
2023-10-07 Updated Assembly and Installation Instructions
    Installation and test info

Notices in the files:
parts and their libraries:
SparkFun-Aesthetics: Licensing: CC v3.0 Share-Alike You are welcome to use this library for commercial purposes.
